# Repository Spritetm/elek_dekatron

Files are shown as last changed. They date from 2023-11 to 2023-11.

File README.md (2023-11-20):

What is this?
-------------

This repo contains the files for a Dekatron bandwidth spinner. It uses an ESP32-C3 to read
out a switch or other network device that talks over SNMP and spins a Dekatron according
to the data flowing over one of its network ports.

Directories in this repo
------------------------

 * case - Contains Fusion360 as well as step and stl files of the case.
 * pcb - Kicad project for the PCB of the spinner
 * firmware - Firmware for the ESP32-C3 in the device. Firmware was compiled using
   ESP-IDF v5.0.4 but you can probably use any v5.x version.

User manual
-----------

After building the PCB, the device needs to be flashed. This can be done by plugging
the USB-C port into a PC while holding the button on the back of the device, then 
flashing as normal. Unplug and replug to start the firmware. After the first succesful
flash, you generally don't need to hold the button when re-flashing.

This device needs to be connected to an USB-PD power supply that can supply 9V or 
more to activate the HV power supply for the Dekatron. If not attached to a 
compatible power supply (e.g. when plugged into a computer), D9 will blink and the 
Dekatron will stay off. The rest of the device will still work, that is, you can
still configure WiFi and SNMP credentials as usual.

On first startup, WiFi needs to be configured. To do this, the device will show
a WiFi access point called 'dekatron'. You can connect to this using a phone or laptop
and it will automatically direct you to a captive webpage where you can select an
access point and enter its password. If the redirect doesn't happen, simply open
a browser and go to http://192.168.4.1/wifi . After you've entered this, the Dekatron
will try to show its best impression of the IP address it got; if you have issues
decyphering this, you can try either connecting to the serial port to see the IP it 
got or checking the DHCP lease table on your router.

The Dekatron will remember the WiFi network and password on subsequent power-ups.
If for some reason you need to change WiFi credentials (e.g. because the original
network is not available anymore, after boot-up simply press and hold the button on
the back of the device for more than 3 seconds, and the 'dekatron' WiFi access point
will show up again.

If you use a webbrowser to connect to the IP, you can configure the SNMP credentials.
Note that you will probably need to change the IP address if your switch, but often the
default community and OIDs will work to use the information of the first network port.
The last decimal of the OID indicates the network port, so increade that to get
another one. Note that some switches don't start counting ports from 1; e.g. my Cisco
starts at 49 instead so the OID for incoming octets on the 2nd network port
I use is .1.3.6.1.2.1.2.2.1.10.50

Here, you can also configure the bandwidth that makes the dekatron spin fastest. You 
can set this to lower than your actual Internet connection can handle; it will simply
spin at its fastests speed for any bandwidth above. Note the bandwidth is in bits 
per second; if you know the bandwidth in bytes per second, simply multiply that by eight.

Finally, you can set a rotation. Some effects (for now only the bit where it shows the
devices IP on the dekatron) assume a a rotation of the physical dekatron. If this is 
wrong, you can adjust it here. Note that the position detection circuit is a bit finnicky,
so depending on your dekatron you may not be able to get this to work stably.

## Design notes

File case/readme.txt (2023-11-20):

Directory contents:
    Dekatron v12.f3d
        This is Fusion360 archive file. You should be able to retrieve an editable file from this
    Dekatron v12.step
        This is a step file. Most 3D CAD software can import this format and recognize features for editing
    Dekatron_case.stl
    Dekatron_cover.stl
        The 2 STL is all you need for 3D printing without modification

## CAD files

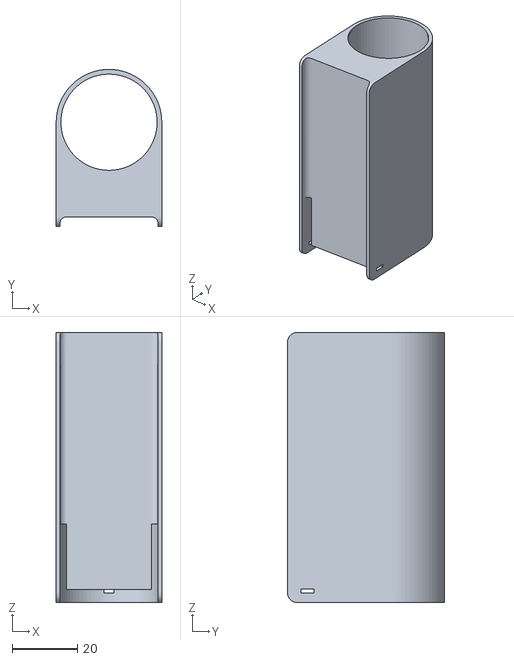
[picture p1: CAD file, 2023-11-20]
case/dekatron_case.stl
32.4 x 48.2 x 82.8

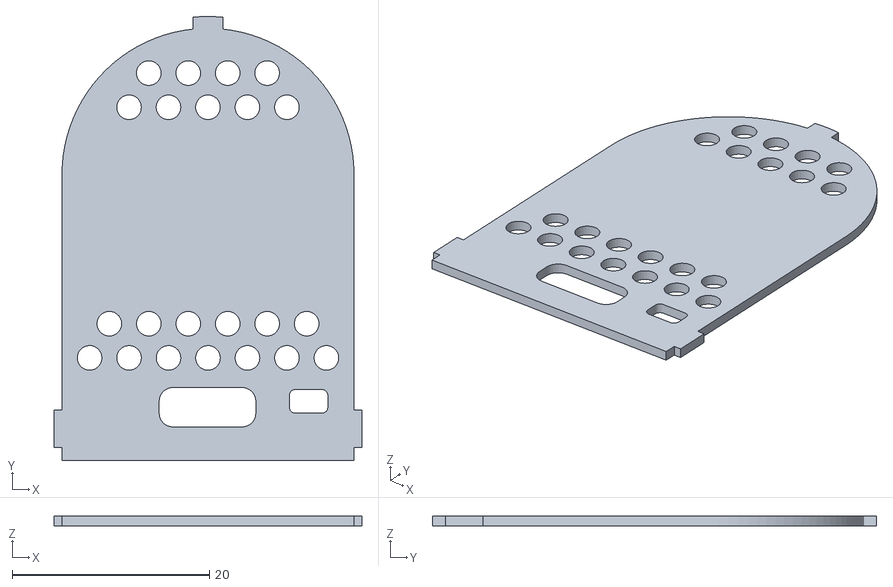
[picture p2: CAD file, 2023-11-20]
case/dekatron_cover.stl
31.2 x 45.0 x 1.00

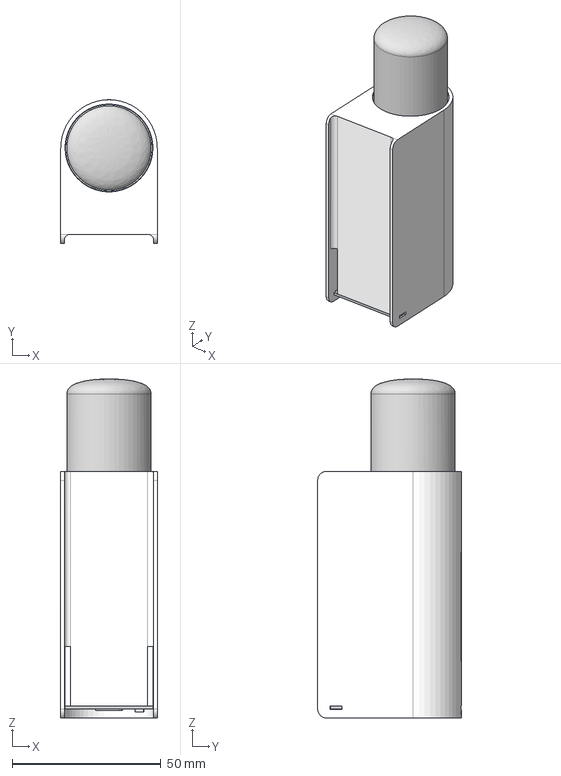
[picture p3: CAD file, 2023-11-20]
case/Dekatron v12.step
32.4 x 48.2 x 113.8 mm

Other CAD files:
case/Dekatron v12.f3d

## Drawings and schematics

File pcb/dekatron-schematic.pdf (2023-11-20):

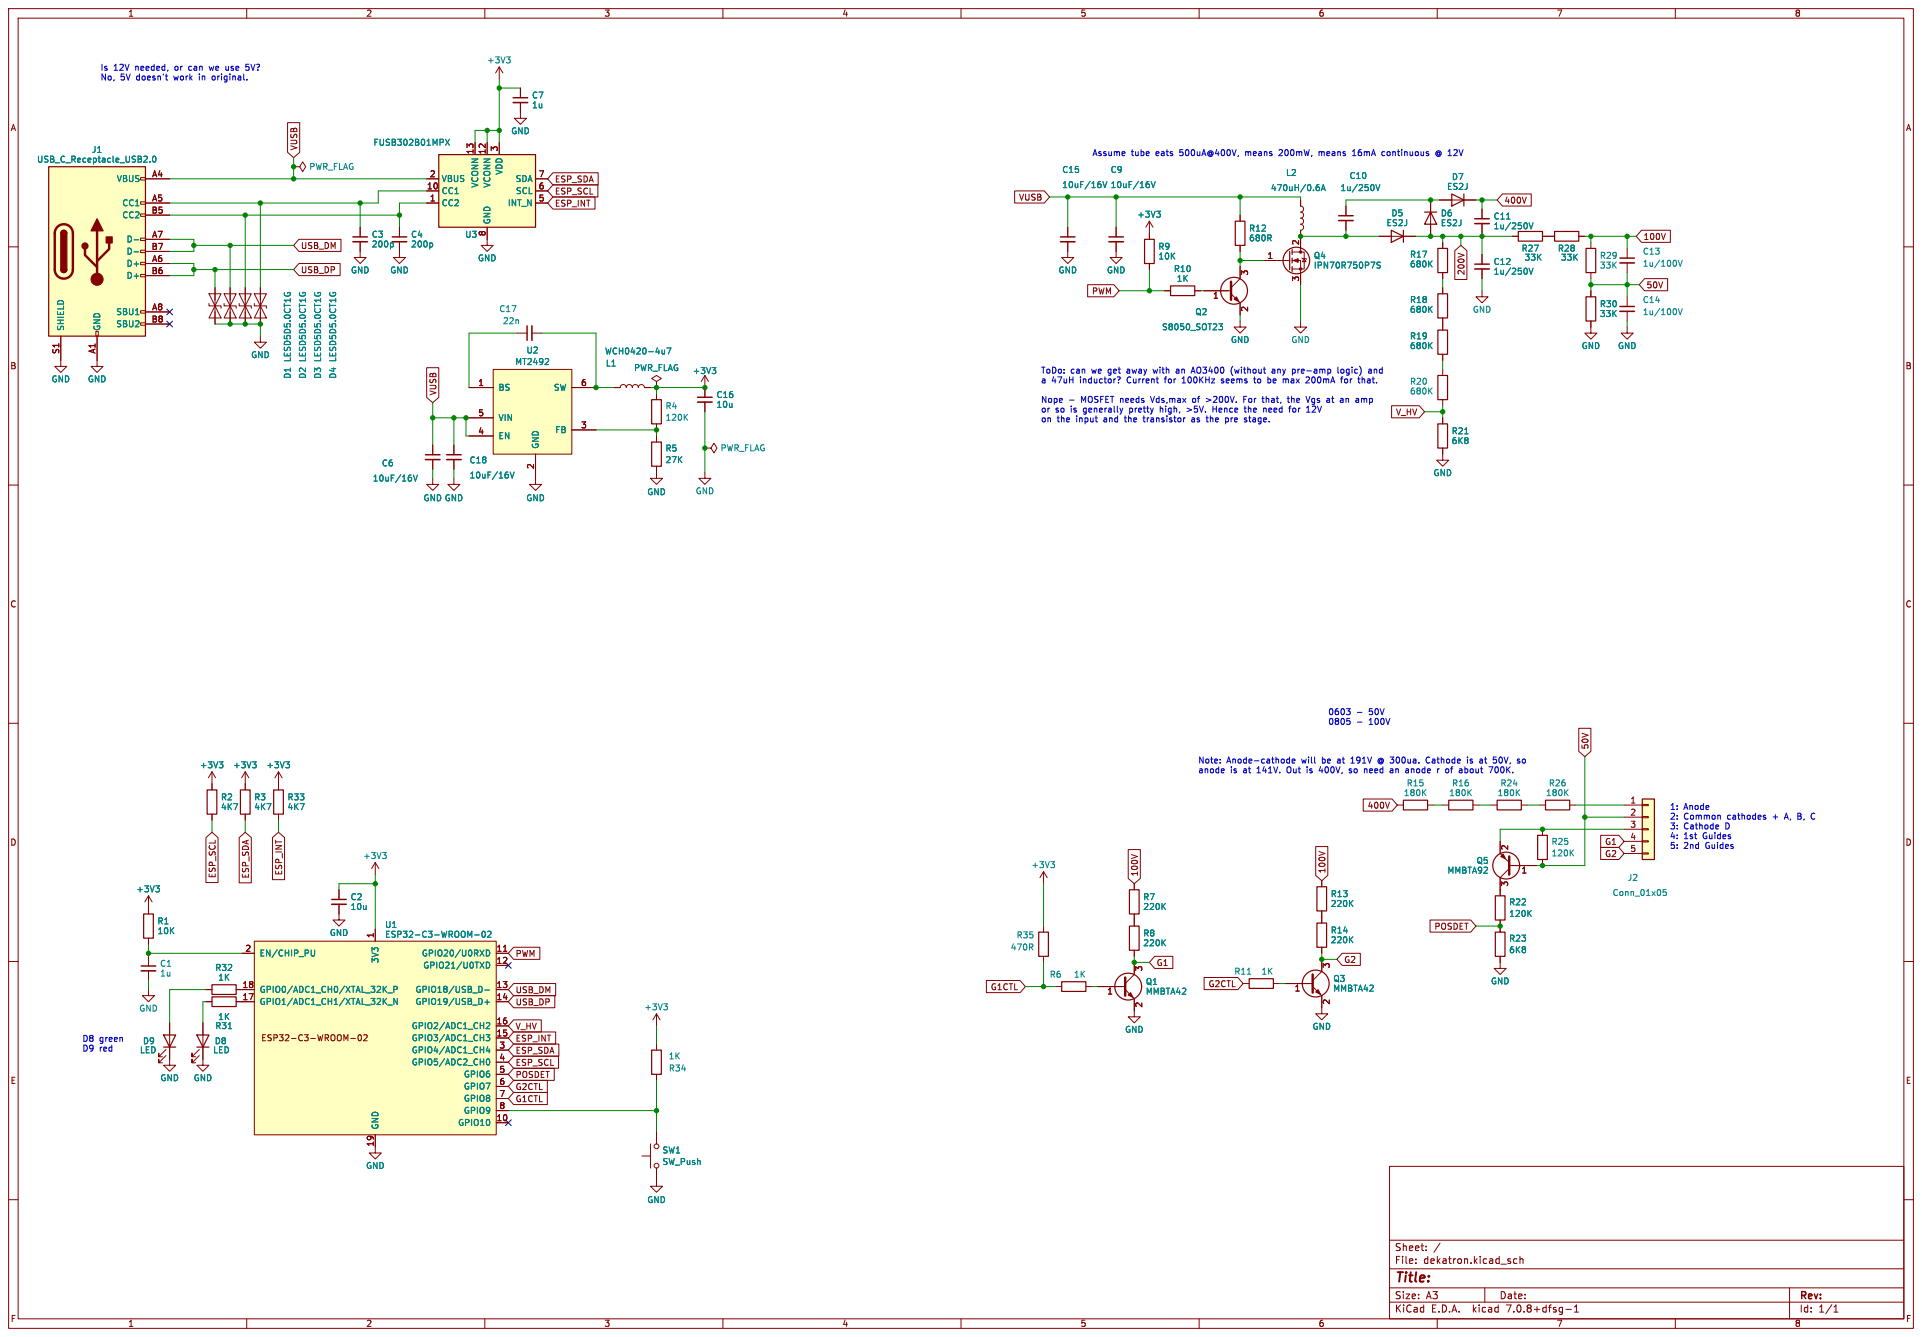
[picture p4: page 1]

Is 12V needed, or can we use 5V? No, 5V doesn't work in original.

2 FB 3 EN 4 VIN 5 SW 6 U2 MT2492 R27
GND

2 FB 3 EN 4 VIN 5 SW 6 GND

anode is at 141V. Out is 400V, so need an anode r of about 700K.

1 GPIO10 10 GPIO20/U0RXD 11 GPIO21/U0TXD 12 GPIO18/USB_D- 13 GPIO19/USB_D+ 14 GPIO3/ADC1_CH3 15 GPIO2/ADC1_CH2 16 GPIO1/ADC1_CH1/XTAL_32K_N 17 GPIO0/ADC1_CH0/XTAL_32K_P 18 GND 19 EN/CHIP_PU 2 GPIO4/ADC1_CH4 3 GPIO5/ADC2_CH0 4 GPIO6 5 GPIO7 6 GPIO8 7 GPIO9 8 U1 GND ESP32-C3-WROOM-02 +3V3 C2

Id: 1/1 Title: File: dekatron.kicad_sch Sheet: /

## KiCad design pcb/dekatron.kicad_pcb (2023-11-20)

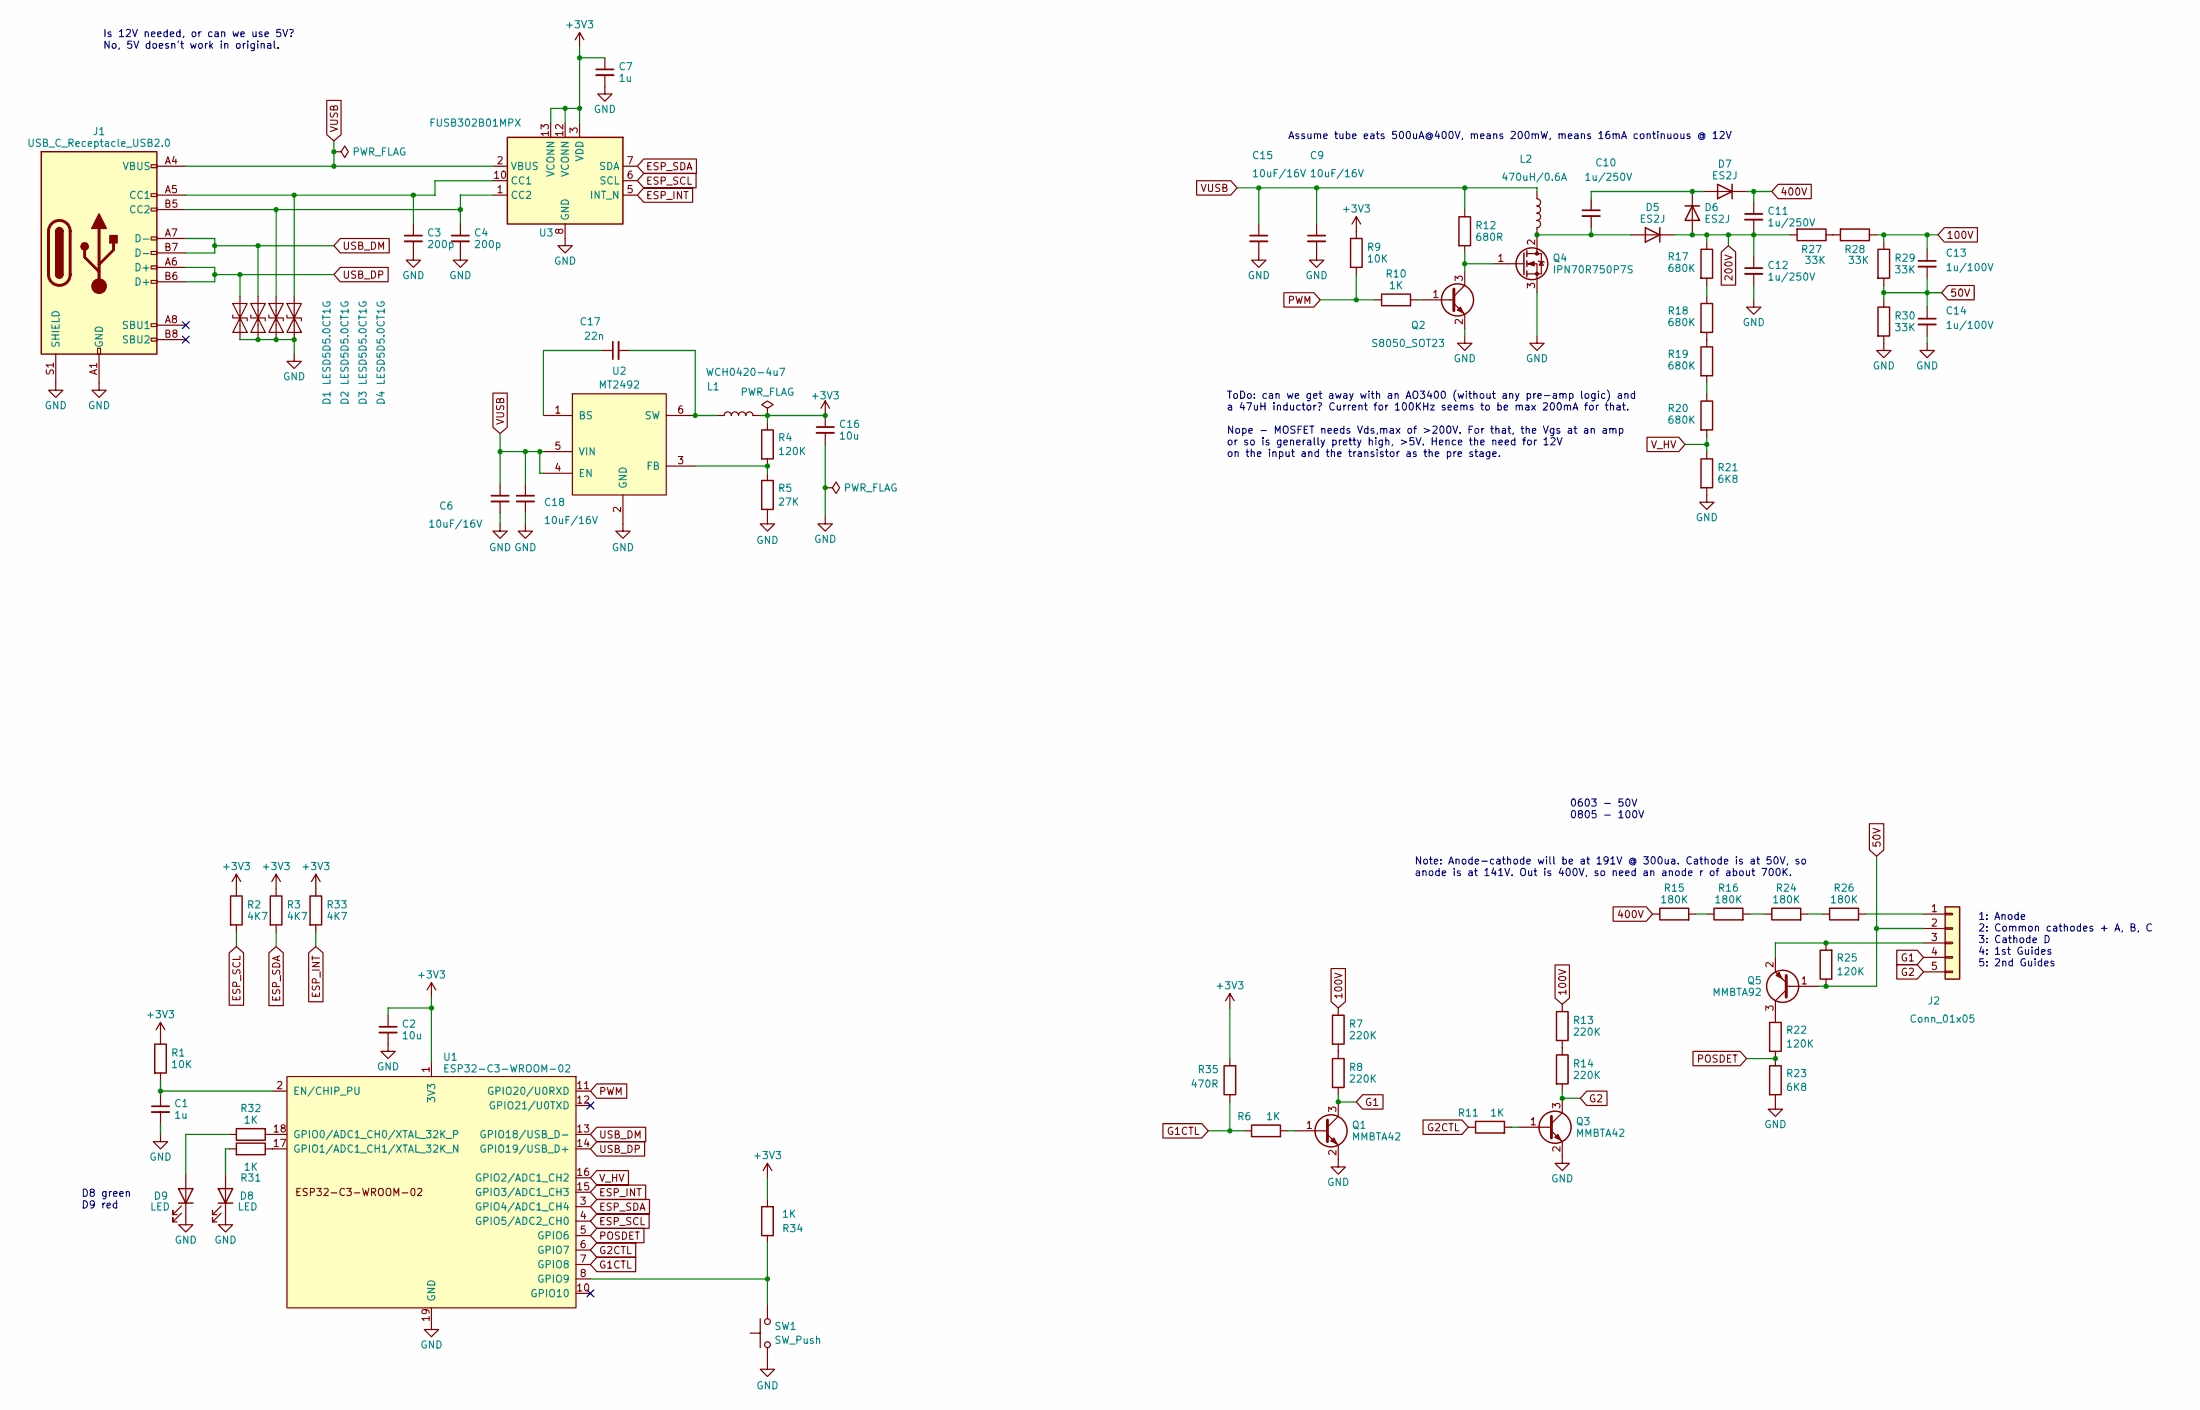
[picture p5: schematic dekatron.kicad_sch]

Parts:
C1, C7: 1u; C_0603_1608Metric
C2, C16: 10u; C_0805_2012Metric
C3, C4: 200p; C_0603_1608Metric
C6, C9, C15, C18: 10uF/16V; C_0805_2012Metric
C10, C11, C12: 1u/250V; C_2220_5650Metric
C13, C14: 1u/100V; C_1210_3225Metric
C17: 22n; C_0603_1608Metric
D1, D2, D3, D4: LESD5D5.0CT1G; D_SOD-523
D5, D6, D7: ES2J; D_SMA
D8, D9: LED; LED_0603_1608Metric
J1: USB_C_Receptacle_USB2.0; USB_C_Receptacle_HRO_TYPE-C-31-M-12
J2: Conn_01x05; PinHeader_1x05_P2.54mm_Vertical
L1: WCH0420-4u7; L_Chilisin_BMRA00040420
L2: 470uH/0.6A; Inductor_CYH127
Q1, Q3: MMBTA42; SOT-23
Q2: S8050_SOT23; SOT-23
Q4: IPN70R750P7S; PG-SOT-223
Q5: MMBTA92; SOT-23
R1, R9: 10K; R_0603_1608Metric
R2, R3, R33: 4K7; R_0603_1608Metric
R4, R22, R25: 120K; R_0603_1608Metric
R5: 27K; R_0603_1608Metric
R6, R10, R11, R31, R32, R34: 1K; R_0603_1608Metric
R7, R8, R13, R14: 220K; R_0603_1608Metric
R12: 680R; R_0603_1608Metric
R15, R16, R24, R26: 180K; R_0603_1608Metric
R17, R18, R19, R20: 680K; R_0603_1608Metric
R21, R23: 6K8; R_0603_1608Metric
R27, R28, R29, R30: 33K; R_0603_1608Metric
R35: 470R; R_0603_1608Metric
SW1: SW_Push; SW_SPST_Omron_B3F-315x_Angled
U1: ESP32-C3-WROOM-02
U2: MT2492; SOT-23-6
U3: FUSB302B01MPX; WQFN-14-1EP_2.5x2.5mm_P0.5mm_EP1.45x1.45mm

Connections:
50V: C13.2, C14.1, J2.2, Q5.1 (B), R25.1, R29.2, R30.1
100V: C13.1, R7.1, R13.1, R28.1, R29.1
200V: C11.2, C12.1, D5.1 (K), D6.2 (A), R17.1, R27.2
400V: C11.1, D7.1 (K), R15.1
+3V3: C2.1, C7.1, C16.1, L1.2, R1.1, R2.1, R3.1, R4.1, R9.1, R33.1, R34.2, R35.2, U1.1 (3V3), U3.3 (VDD), U3.4 (VDD), U3.12 (VCONN), U3.13 (VCONN)
ESP_INT: R33.2, U1.15 (GPIO3/ADC1_CH3), U3.5 (INT_N)
ESP_SCL: R2.2, U1.4 (GPIO5/ADC2_CH0), U3.6 (SCL)
ESP_SDA: R3.2, U1.3 (GPIO4/ADC1_CH4), U3.7 (SDA)
G1: J2.4, Q1.3 (C), R8.2
G1CTL: R6.1, R35.1, U1.7 (GPIO8)
G2: J2.5, Q3.3 (C), R14.2
G2CTL: R11.1, U1.6 (GPIO7)
GND: C1.2, C2.2, C3.2, C4.2, C6.2, C7.2, C9.2, C12.2, C14.2, C15.2, C16.2, C18.2, D1.1 (A1), D2.1 (A1), D3.1 (A1), D4.1 (A1), D8.1 (K), D9.1 (K), J1.A1 (GND), J1.A12 (GND), J1.B1 (GND), J1.B12 (GND), J1.S1 (SHIELD), Q1.2 (E), Q2.2 (E), Q3.2 (E), Q4.3 (S), R5.2, R21.2, R23.2, R30.2, SW1.1, U1.9 (GND), U1.19 (GND), U2.2 (GND), U3.8 (GND), U3.9 (GND), U3.15 (GND)
unnamed: C4.1, D3.2 (A2), J1.B5 (CC2), U3.1 (CC2), U3.14 (CC2)
unnamed: C3.1, D4.2 (A2), J1.A5 (CC1), U3.10 (CC1), U3.11 (CC1)
unnamed: C10.2, D5.2 (A), L2.2, Q4.2 (D)
unnamed: C10.1, D6.1 (K), D7.2 (A)
unnamed: D8.2 (A), R31.2
unnamed: D9.2 (A), R32.1
unnamed: J2.1, R26.2
unnamed: J2.3, Q5.2 (E), R25.2
unnamed: Q1.1 (B), R6.2
unnamed: Q2.1 (B), R10.2
unnamed: Q2.3 (C), Q4.1 (G), R12.2
unnamed: Q3.1 (B), R11.2
unnamed: Q5.3 (C), R22.1
unnamed: R7.2, R8.1
unnamed: R13.2, R14.1
unnamed: R15.2, R16.1
unnamed: R16.2, R24.1
unnamed: R17.2, R18.1
unnamed: R18.2, R19.1
unnamed: R19.2, R20.1
unnamed: R24.2, R26.1
unnamed: R27.1, R28.2
unnamed: C1.1, R1.2, U1.2 (EN/CHIP_PU)
unnamed: R32.2, U1.18 (GPIO0/ADC1_CH0/XTAL_32K_P)
unnamed: R31.1, U1.17 (GPIO1/ADC1_CH1/XTAL_32K_N)
unnamed: R34.1, SW1.2, U1.8 (GPIO9)
unnamed: C17.1, U2.1 (BS)
unnamed: R4.2, R5.1, U2.3 (FB)
unnamed: C17.2, L1.1, U2.6 (SW)
POSDET: R22.2, R23.1, U1.5 (GPIO6)
PWM: R9.2, R10.1, U1.11 (GPIO20/U0RXD)
USB_DM: D2.2 (A2), J1.A7 (D-), J1.B7 (D-), U1.13 (GPIO18/USB_D-)
USB_DP: D1.2 (A2), J1.A6 (D+), J1.B6 (D+), U1.14 (GPIO19/USB_D+)
VUSB: C6.1, C9.1, C15.1, C18.1, J1.A4 (VBUS), J1.A9 (VBUS), J1.B4 (VBUS), J1.B9 (VBUS), L2.1, R12.1, U2.4 (EN), U2.5 (VIN), U3.2 (VBUS)
V_HV: R20.2, R21.1, U1.16 (GPIO2/ADC1_CH2)

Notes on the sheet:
D8 green D9 red
Is 12V needed, or can we use 5V? No, 5V doesn't work in original.
Assume tube eats 500uA@400V, means 200mW, means 16mA continuous @ 12V
ToDo: can we get away with an AO3400 (without any pre-amp logic) and a 47uH inductor? Current for 100KHz seems to be max 200mA for that. Nope - MOSFET needs Vds,max of >200V. For that, the Vgs at an amp or so is generally pretty high, >5V. Hence the need for 12V on the input and the transistor as t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
1: Anode 2: Common cathodes + A, B, C 3: Cathode D 4: 1st Guides 5: 2nd Guides
Note: Anode-cathode will be at 191V @ 300ua. Cathode is at 50V, so anode is at 141V. Out is 400V, so need an anode r of about 700K.
0603 - 50V 0805 - 100V

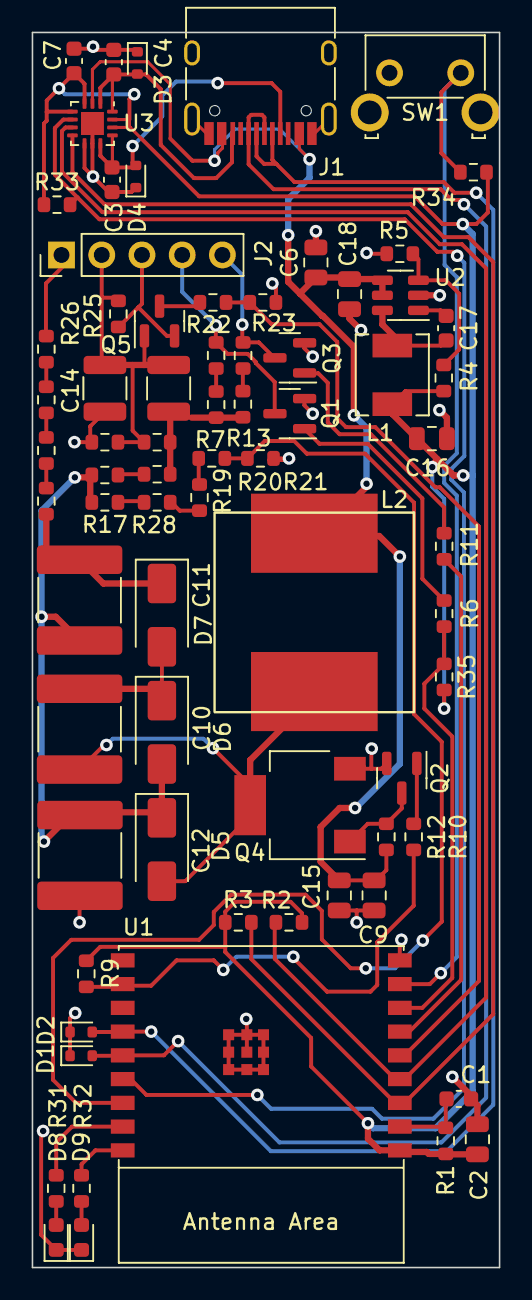
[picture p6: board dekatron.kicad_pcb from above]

Board: 2 copper layers, 29.5 x 78.0 mm, 73 parts (0 on the bottom side), 48 nets.

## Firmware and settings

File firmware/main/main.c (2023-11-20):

/*
 * ----------------------------------------------------------------------------
 * "THE BEER-WARE LICENSE" (Revision 42):
 * Jeroen Domburg <jeroen@spritesmods.com> wrote this file. As long as you retain 
 * this notice you can do whatever you want with this stuff. If we meet some day, 
 * and you think this stuff is worth it, you can buy me a beer in return. 
 * ----------------------------------------------------------------------------
 */

#include <stdio.h>
#include <string.h>
#include "driver/ledc.h"
#include "esp_err.h"
#include "esp_log.h"
#include "esp_timer.h"
#include "esp_adc/adc_oneshot.h"
#include "esp_adc/adc_cali.h"
#include "esp_adc/adc_cali_scheme.h"
#include "freertos/FreeRTOS.h"
#include "freertos/task.h"
#include "usbpd_esp.h"
#include "driver/i2c.h"
#include "dekatron.h"
#include "esp_netif_types.h"
#include "wifi_manager.h"
#include "driver/gpio.h"
#include "snmpgetter.h"
#include "webconfig.h"
#include "io.h"

static const char *TAG="main";

static SemaphoreHandle_t deka_start_sema;

/*
Callback for USB-PD driver. We want 12V but are also happy with 9 or 15V.
*/
static int prefered_idx=0;
static int usbpd_cb(int type, int mv, int ma) {
	const int preference[]={15000, 9000, 12000, 0}; //most prefered is last
	if (type==USBPD_ESP_CB_INITIAL) prefered_idx=0;
	if (type==USBPD_ESP_CB_CHOSEN) {
		ESP_LOGI(TAG, "Chosen USB-PD config: %d mV @ %d mA", mv, ma);
		webconfig_set_usbpd(mv, ma);
		//If we picked something compatible, turn led off, if not blink fast.
		int can_start=0;
		io_led_blink_set(LED_RED, BLINK_FAST);
		for (int i=0; preference[i]!=0; i++) {
			if (preference[i]==mv) {
				io_led_blink_set(LED_RED, BLINK_OFF);
				can_start=1;
			}
		}
		if (can_start) xSemaphoreGive(deka_start_sema);
	} else {
		for (int i=0; preference[i]!=0; i++) {
			if (mv==preference[i] && prefered_idx<=i) {
				prefered_idx=i;
				return 1; //pick this one
			}
		}
	}
	return 0;
}

//Connection state, to blink the green LED. Note that the flags are set from
//various threads, so we need a mux to serialize access.
#define FLAG_CONNECTED (1<<0)
#define FLAG_AP (1<<1)
#define FLAG_SNMP (1<<2)
static int conn_flags=0;
static SemaphoreHandle_t conn_flag_mutex;

static void set_conn_flag(int bitmask, int set) {
	xSemaphoreTake(conn_flag_mutex, portMAX_DELAY);
	if (set) conn_flags|=bitmask; else conn_flags&=~bitmask;
	printf("Conn flags %x\n", conn_flags);
	if (conn_flags&FLAG_AP) {
		io_led_blink_set(LED_GREEN, BLINK_ON);
	} else if ((conn_flags&FLAG_CONNECTED)==0) {
		io_led_blink_set(LED_GREEN, BLINK_SLOW);
	} else if ((conn_flags&FLAG_SNMP)==0) {
		io_led_blink_set(LED_GREEN, BLINK_FAST);
	} else {
		io_led_blink_set(LED_GREEN, BLINK_OFF);
	}
	xSemaphoreGive(conn_flag_mutex);
}

//Callback for when we have a network connection.
static void cb_connection_ok(void *pvParameter) {
	ip_event_got_ip_t* param = (ip_event_got_ip_t*)pvParameter;
	char str_ip[32];
	esp_ip4addr_ntoa(&param->ip_info.ip, str_ip, 32);
	ESP_LOGI(TAG, "I have a connection and my IP is %s!", str_ip);
	for (int i=0; str_ip[i]!=0; i++) {
		deka_queue_anim(DEKA_ANIM_TYPE_CHAR, str_ip[i], 10000, 2000);
	}
	deka_queue_anim(DEKA_ANIM_TYPE_SPIN, 0, 10000, 0);
	set_conn_flag(FLAG_CONNECTED, 1);
}

static void cb_connection_disconnected(void *pvParameter) {
	set_conn_flag(FLAG_CONNECTED, 0);
}

static void cb_connection_apstart(void *pvParameter) {
	set_conn_flag(FLAG_AP, 1);
}

static void cb_connection_apstop(void *pvParameter) {
	set_conn_flag(FLAG_AP, 0);
}


static void dekatron_start() {
	ESP_LOGI(TAG, "Snmpgetter start");
	char snmpip[256], community[256], oid_in[256], oid_out[256];
	webconfig_get_config_str("snmpip", snmpip, sizeof(snmpip));
	webconfig_get_config_str("community", community, sizeof(community));
	webconfig_get_config_str("oid_in", oid_in, sizeof(oid_in));
	webconfig_get_config_str("oid_out", oid_out, sizeof(oid_out));
	ESP_LOGI(TAG, "Using config snmpip=%s community=%s oid_in=%s oid_out=%s", 
			snmpip, community, oid_in, oid_out);
	snmpgetter_start(snmpip, 161, community, oid_in, oid_out);
	char rot_str[16];
	webconfig_get_config_str("rotation", rot_str, sizeof(rot_str));
	deka_set_rotation(atoi(rot_str));
}

//This allows you to enter something like '0.92G' and it'll parse it to a proper
//value.
static uint64_t get_max_bw() {
	char bw_str[16];
	webconfig_get_config_str("max_bw_bps", bw_str, sizeof(bw_str));
	float f=atof(bw_str);
	char ind=bw_str[strlen(bw_str)-1];
	if (ind=='g' || ind=='G') f=f*1024*1024*1024;
	if (ind=='m' || ind=='M') f=f*1024*1024;
	if (ind=='k' || ind=='K') f=f*1024;
	return f;
}



#define PRESS_DUR_LONG 30 //3 seconds
//called every 100ms
void btn_callback(void *arg) {
	static int press_dur=0;
	if (io_btn_pressed()) {
		press_dur++;
		if (press_dur==PRESS_DUR_LONG) {
			//long pressed
			wifi_manager_send_message(WM_ORDER_DISCONNECT_STA, NULL);
			wifi_manager_send_message(WM_ORDER_START_AP, NULL);
		}
	} else {
		if (press_dur!=0 && press_dur<PRESS_DUR_LONG) {
			//short pressed
		}
		press_dur=0;
	}
}

void app_main(void) {
	io_init();
	io_led_blink_set(LED_RED, BLINK_SLOW);
	io_led_blink_set(LED_GREEN, BLINK_SLOW);
	
	deka_start_sema=xSemaphoreCreateBinary();
	conn_flag_mutex=xSemaphoreCreateMutex();
	const esp_timer_create_args_t btn_timer_args = {
		.callback = &btn_callback,
		.name = "btn"
	};
	esp_timer_handle_t btn_timer;
	ESP_ERROR_CHECK(esp_timer_create(&btn_timer_args, &btn_timer));
	ESP_ERROR_CHECK(esp_timer_start_periodic(btn_timer, 100000));

	deka_init();

	int i2c_master_port = 0;

	i2c_config_t conf = {
		.mode = I2C_MODE_MASTER,
		.sda_io_num = 4,
		.scl_io_num = 5,
		.sda_pullup_en = GPIO_PULLUP_ENABLE,
		.scl_pullup_en = GPIO_PULLUP_ENABLE,
		.master.clk_speed = 400000,
	};
	ESP_ERROR_CHECK(i2c_param_config(i2c_master_port, &conf));
	ESP_ERROR_CHECK(i2c_driver_install(i2c_master_port, conf.mode, 0, 0, 0));
	ESP_ERROR_CHECK(usbpd_esp_init(i2c_master_port, usbpd_cb));

	wifi_manager_start();
	wifi_manager_set_callback(WM_EVENT_STA_GOT_IP, &cb_connection_ok);
	wifi_manager_set_callback(WM_ORDER_DISCONNECT_STA, &cb_connection_disconnected);
	wifi_manager_set_callback(WM_ORDER_START_AP, &cb_connection_apstart);
	wifi_manager_set_callback(WM_ORDER_STOP_AP, &cb_connection_apstop);
	webconfig_start();

	dekatron_start();

	//note: field is in *bit* per second so we convert to *bytes* per second as
	//everything else is in bytes per second as well.
	uint64_t max_bw_bps=get_max_bw()/8;

	//Wait for succesful USB PD negotiation to start HV PSU
	ESP_LOGI(TAG, "Wait for USB-PD negotiations");
	set_conn_flag(FLAG_SNMP, 1); //to stop blinking green LED
	xSemaphoreTake(deka_start_sema, portMAX_DELAY);
	deka_start();

	ESP_LOGI(TAG, "Snmpgetter query start");
	while(1) {
		snmpgetter_bw_t bw;
		int r=0;
		do {
			r=snmpgetter_get_bw(&bw, pdMS_TO_TICKS(2000));
			set_conn_flag(FLAG_SNMP, r);
		} while (!r);
		ESP_LOGI(TAG, "in %d Kbps out %d Kbps", bw.bps_in/1024, bw.bps_out/1024);
		float max_speed_rps=20;
		float speed_in_rps=(max_speed_rps*bw.bps_in)/max_bw_bps;
		float speed_out_rps=(max_speed_rps*bw.bps_out)/max_bw_bps;
		float speed_rps=(speed_in_rps>speed_out_rps)?speed_in_rps:speed_out_rps;
		if (speed_rps>max_speed_rps) speed_rps=max_speed_rps;
		if (speed_rps<0.01) speed_rps=0.01; //don't divide by zero
		int delay_us=((1000000.0/30)/speed_rps);
		//printf("speed_rps %f delay %d\n", speed_rps, delay_us);
		deka_queue_anim(DEKA_ANIM_TYPE_SPIN, (bw.bps_in>bw.bps_out)?1:0, delay_us, 0);
		vTaskDelay(pdMS_TO_TICKS(500));
	}
}

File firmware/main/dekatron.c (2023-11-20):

/*
 * ----------------------------------------------------------------------------
 * "THE BEER-WARE LICENSE" (Revision 42):
 * Jeroen Domburg <jeroen@spritesmods.com> wrote this file. As long as you retain 
 * this notice you can do whatever you want with this stuff. If we meet some day, 
 * and you think this stuff is worth it, you can buy me a beer in return. 
 * ----------------------------------------------------------------------------
 */

#include "dekatron.h"
#include <stdio.h>
#include <stdint.h>
#include <stdatomic.h>
#include "driver/ledc.h"
#include "esp_err.h"
#include "esp_log.h"
#include "esp_adc/adc_oneshot.h"
#include "esp_adc/adc_cali.h"
#include "esp_adc/adc_cali_scheme.h"
#include "freertos/FreeRTOS.h"
#include "freertos/task.h"
#include "freertos/queue.h"
#include "usbpd_esp.h"
#include "driver/i2c.h"
#include "driver/gptimer.h"
#include <math.h>
#include <string.h>
#include "esp_timer.h"
#include "driver/gpio.h"
#include "io.h"

static const char *TAG="dekatron";


/*
For Fancy Animations (tm):
The datasheet states 4K PPS max rate. Given that this is probably 1 pulse per 1/10th dekatron, if we
use it as 1/30th we can use 12K PPS max. This means 83uS minimum per cathode. The datasheets specs
a 'double pulse drive duration' fo 60uS, so we're within that. (Note the way with G1/G2 is called
'double pulse'.)

Say we want to have a minimum refresh rate of 100Hz, for half the cathodes 'fully' lit. That means
we need to rotate through 15 cathodes at 100Hz*15=1.5KHz. This means 666 uS max per cathode. This is
flexible, however, given we may want less max cathodes fully lit for a better bright/'off' contrast.
*/

#define PULSE_MIN_US 83
#define PULSE_MAX_US 666

#define TIME_ONE_FRAME_US (1000000/60)

#define NO_FIXED_TARGET -1
static int curr_cathode=0;
static int fixed_target=1;
static int delay_per_cathode_us[30]={0};
static char g1_for[30];
static char g2_for[30];
static int rotation=0;
static int posdet_hit[30]={0};
static int posdet_hit_total=0;
static int posdet_prev=0;
static int curr_pwm=0;
atomic_int rot_corr=0;

typedef struct {
	char c;
	uint32_t lit;
} font_ent_t;

static const font_ent_t font[]={
	{'0', 0x3FFFFFFF},
	{'1', 0xff0},
	{'2', 0x3c7fe0ff},
	{'3', 0x3c47fc7f},
	{'4', 0x3fc08001},
	{'5', 0x3f8fff07},
	{'6', 0x3fffff07},
	{'7', 0x38000fff},
	{'8', 0x3f3ffe7f},
	{'9', 0x3f01fe7f},
	{'.', 0x2000},
	{' ', 0},
	{0, 0}, //default
};

static bool IRAM_ATTR timer_cb(gptimer_handle_t timer, const gptimer_alarm_event_data_t *edata, void *user_data) {
	int delay;
	if (!gpio_get_level(IO_POSDET)) {
		if (!posdet_prev) {
			posdet_hit[curr_cathode]++;
			posdet_hit_total++;
		}
		posdet_prev=1;
	} else {
		posdet_prev=0;
	}
	curr_cathode+=atomic_exchange(&rot_corr, 0);
	if (fixed_target==NO_FIXED_TARGET) {
		//Simply walk through the electrodes, lighting them up for the specified time
		curr_cathode++;
		if (curr_cathode>=30) curr_cathode=0;
		delay=delay_per_cathode_us[curr_cathode];
	} else {
		//Count towards the fixed target
		int pulses_fwd=(fixed_target-curr_cathode);
		if (pulses_fwd<0) pulses_fwd+=30;
		if (pulses_fwd==0) {
			delay=PULSE_MAX_US;
		} else if (pulses_fwd<15) {
			curr_cathode++;
			if (curr_cathode>=30) curr_cathode=0;
			delay=PULSE_MIN_US;
		} else {
			curr_cathode--;
			if (curr_cathode<0) curr_cathode=29;
			delay=PULSE_MIN_US;
		}
	}
	gpio_set_level(IO_G2, g2_for[curr_cathode]);
	gpio_set_level(IO_G1, g1_for[curr_cathode]);

	// reconfigure alarm value
	gptimer_alarm_config_t alarm_config = {
		.alarm_count = edata->alarm_value + delay
	};
	gptimer_set_alarm_action(timer, &alarm_config);
	return true;
}

static void deka_set_pos(int pos) {
	pos=pos%30;
	if (pos<0) pos+=30;
	fixed_target=pos;
}

static void deka_set_intens(uint8_t *intens) {
	//This tries to set the timings so one 'frame' (decatron making a full circle) takes
	//up TIME_ONE_FRAME_US time. It does that by trying to maximise the time the 
	//non-zero-intensity cathodes are lit.
	int total_intens=0;
	for (int i=0; i<30; i++) {
		total_intens+=intens[i];
	}

	int time_left=TIME_ONE_FRAME_US-(30*PULSE_MIN_US);
	for (int i=0; i<30; i++) {
		delay_per_cathode_us[i]=PULSE_MIN_US+((intens[i]*time_left)/total_intens);
	}
	fixed_target=NO_FIXED_TARGET;
}



typedef struct {
	int type;
	int subtype;
	int speed; //actually delay in us
	int duration_ms;
} deka_cmd_t;

QueueHandle_t deka_cmd_queue;


static void ledc_init(void) {
	ledc_timer_config_t ledc_timer = {
		.speed_mode		  = LEDC_LOW_SPEED_MODE,
		.timer_num		  = LEDC_TIMER_0,
		.duty_resolution  = LEDC_TIMER_9_BIT,
		.freq_hz		  = 40000,
		.clk_cfg		  = LEDC_AUTO_CLK
	};
	ESP_ERROR_CHECK(ledc_timer_config(&ledc_timer));

	ledc_channel_config_t ledc_channel = {
		.speed_mode		= LEDC_LOW_SPEED_MODE,
		.channel		= LEDC_CHANNEL_0,
		.timer_sel		= LEDC_TIMER_0,
		.intr_type		= LEDC_INTR_DISABLE,
		.gpio_num		= IO_BOOST,
		.duty			= 256
	};
	ESP_ERROR_CHECK(ledc_channel_config(&ledc_channel));
}


static adc_oneshot_unit_handle_t adc1_handle;
static adc_cali_handle_t adc_cali_handle;

static void deka_power_task(void *arg) {
	int duty=256;	//current duty cycle
	//Note that duty is inverted, as in, duty being high generally results in a low boost
	//output voltage and vice versa.
	int tgt=480;	//equivalent of 400V
	int warned=0;
	int posdet_fix_tmr=0;
	while(1) {
		int adc_raw, voltage;
		ESP_ERROR_CHECK(adc_oneshot_read(adc1_handle, IO_ADC_HV, &adc_raw));
		ESP_ERROR_CHECK(adc_cali_raw_to_voltage(adc_cali_handle, adc_raw, &voltage));

		//Very slow and simple regulation loop. It's fine, there is a fair amount of tolerance
		//on the dekatron voltages, and the fact that this starts a bit slow generally is
		//acceptable.
		if (voltage<tgt) duty--; else duty++;
		
		//upper and lower bound for duty, so we don't blow up the boost transistor
		//if e.g. the adc reads the wrong value somehow
		if (duty<15) {
			duty=15;
			if (!warned) {
				ESP_LOGW(TAG, "PWM duty cycle bumped against max limit!");
				warned=1;
			}
		}
		if (duty>511) duty=511;
		//Set the duty cycle and wait.
		ESP_ERROR_CHECK(ledc_set_duty(LEDC_LOW_SPEED_MODE, LEDC_CHANNEL_0, duty));
		ESP_ERROR_CHECK(ledc_update_duty(LEDC_LOW_SPEED_MODE, LEDC_CHANNEL_0));
		curr_pwm=duty;
		vTaskDelay(pdMS_TO_TICKS(50));


		posdet_fix_tmr++;
		if (posdet_fix_tmr>30) {
			posdet_fix_tmr=0;
			int max_hits=0;
			int max_hit_pos=0;
			for (int i=0; i<30; i++) {
				int j=posdet_hit[i];
				posdet_hit[i]=0;
				if (j>max_hits) {
					max_hits=j;
					max_hit_pos=0;
				}
			}
			if (max_hits>5) {
				int c=rotation-max_hit_pos;
				if (c<0) c+=30;
				atomic_fetch_add(&rot_corr, c);
			}
		}
	}
}


static TaskHandle_t deka_anim_task_handle;

void IRAM_ATTR esp_timer_cb(void *arg) {
	int hi_prio_awoken=0;
	vTaskNotifyGiveIndexedFromISR(deka_anim_task_handle, 0, &hi_prio_awoken)
	if (hi_prio_awoken) esp_timer_isr_dispatch_need_yield();
}
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

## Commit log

2023-11-20 Small fix to make the boot button succesfully boot into download mode
    [dekatron.kicad_pcb, dekatron.kicad_sch]
2023-11-20 Lots of fixes, add button support, add LED support, hook up SNMP to Dekatron
    [dekatron.c, io.c, io.h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]
2023-11-20 Add files for 3d-printed case
    [Dekatron v12.f3d, Dekatron v12.step, dekatron_case.stl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]
2023-11-20 Add schematic pdf
2023-11-20 Write readme
    [dekatron.kicad_pcb, dekatron.kicad_sch]

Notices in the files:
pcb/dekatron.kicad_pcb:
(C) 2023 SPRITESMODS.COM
